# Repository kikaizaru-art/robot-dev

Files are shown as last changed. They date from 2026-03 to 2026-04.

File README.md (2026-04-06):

# CoreS3 コンパニオンロボット

M5Stack CoreS3 を使った LOVOT 風コンパニオンロボットのプロトタイプ。
カメラで人を検知し、表情を変え、声で会話し、首や腕を動かす。

## ハードウェア構成

| パーツ | 用途 |
|---|---|
| M5Stack CoreS3 | メインコントローラ (ESP32-S3, LCD, カメラ, マイク, スピーカー) |
| PCA9685 | I2C サーボドライバ |
| MG90S × 4 | 首ヨー/チルト + 左右腕 |
| FS90R × 2 | 走行用連続回転サーボ (予定) |
| ボールキャスター × 1 | 後輪 |

## 機能

- **表情アニメーション** — 6種類 (NORMAL / HAPPY / SAD / SURPRISED / SLEEPY / LOVE)、プロシージャル生成
- **顔検知 & 追従** — ML顔検知 + 肌色/動体検出、5段階の存在レベル判定
- **サーボ連動** — 検知した顔を首で追従、表情に連動した腕アニメーション
- **音声会話** — Gemini API (TTS) による日本語音声対話
- **タッチ & 音反応** — タッチで表情変化、大きな音で驚く
- **OTA更新** — WiFi経由でファームウェア書き込み

## ディレクトリ構成

```
src/             ファームウェア (PlatformIO, Arduino framework)
  main.cpp       メインループ: 検知→表情→サーボ制御
  face.h         LCD表情アニメーションエンジン
  camera_detect.h  顔検知・存在判定
  servo_ctrl.h   サーボ制御・アニメーション
  voice_chat.h   Gemini API 音声会話
chassis/         筐体 CAD (CadQuery → STEP → Fusion 360)
  assembly_v2.py メインアセンブリ
  parts/         個別パーツモデル (MG90S, FS90R, CoreS3 等)
assets/          表情画像 (PNG + RGB565)
data/            SPIFFS用表情データ
```

## ビルド

```bash
# ファームウェア書き込み (WiFi OTA)
pio run --target upload

# サーボテスト
pio run -e servo-test --target upload

# PCA9685テスト
pio run -e pca9685-test --target upload

# シリアルモニタ
pio device monitor -b 115200
```

## 開発状況

プロトタイプ開発中。ファームウェアは動作確認済み、筐体は CAD 設計完了・組み立て検証中。

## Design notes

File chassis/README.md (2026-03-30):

# CoreS3 コンパニオンロボット 筐体設計

## 構成

3分割構造:
1. **ベースプレート** — FS90R駆動輪×2 + ボールキャスター
2. **ボディシェル** — 腕サーボ×2 + PCA9685 + 配線
3. **ヘッドマウント** — CoreS3をスライドイン固定、パンチルト接続

## ファイル

- `robot_chassis.scad` — OpenSCAD設計ファイル（全パーツ統合）

## OpenSCADで開く

```bash
openscad chassis/robot_chassis.scad
```

## STLエクスポート（印刷用）

```bash
cd chassis
openscad -D "show_base=true;show_body=false;show_head=false;show_components=false" -o base.stl robot_chassis.scad
openscad -D "show_body=true;show_base=false;show_head=false;show_components=false" -o body.stl robot_chassis.scad
openscad -D "show_head=true;show_base=false;show_body=false;show_components=false" -o head.stl robot_chassis.scad
```

## サイズ

| パーツ | サイズ(mm) |
|---|---|
| ベース | 105 x 90 x 25 |
| ボディ | 90 x 75 x 55 |
| ヘッド | ~63 x ~47 x 50 |
| 全高 | ~160mm |

## 買い足しパーツ

| パーツ | 数量 | 価格目安 |
|---|---|---|
| PCA9685互換品 | 1 | 500-1,000 |
| MG90Sサーボ | 3 | 1,500 |
| FS90R連続回転サーボ | 2 | 800-1,200 |
| FS90R用タイヤ | 2 | 300-500 |
| ボールキャスター(小) | 1 | 100-300 |
| パンチルトブラケット | 1 | 300-600 |
| 5V 3A電源 | 1 | 500-1,000 |
| **合計** | | **4,000-6,100** |

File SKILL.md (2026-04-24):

---
name: robot-dev
description: M5Stack CoreS3 をベースにした LOVOT 風コンパニオンロボットのプロトタイプ開発プロジェクト。子供たち向けのデスクサイズロボットで、感情表現・顔検知追従・サーボ駆動・音声対話を実装している。次のキーワードや話題が出たときに発動すること： 「ロボット」「コンパニオンロボット」「LOVOT」「CoreS3」「M5Stack」「ESP32-S3」「PCA9685」「MG90S」「FS90R」「サーボ」「パンチルト」「ヨー軸」「筐体」「シャーシ」「CadQuery」「3Dプリント」「Bambu」「ユニバーサルプレート」「表情アニメーション」「顔検知」「Gemini 音声対話」「PlatformIO」「OTA」「ArduinoOTA」。ハード設計・ファームウェア・筐体CAD・機構・購入リスト・商品化方針など、このロボット製作に関する全般の相談相手となる。
---

# CoreS3 コンパニオンロボット (robot-dev)

## プロジェクトの目的
M5Stack CoreS3 をメインコントローラとし、LOVOT のような「そこにいるだけで可愛い」コンパニオンロボットを自作するプロトタイプ。子供たち向けのデスクサイズ玩具として、カメラで人を検知して顔を追い、表情を変え、音で反応し、腕や首を動かし、Gemini API で日本語の音声対話ができる。

最終的には商品化も視野に入れており、USB-C PD 充電、バッテリー駆動、足回り（FS90R 連続回転サーボ + ボールキャスター）への拡張を計画している。まずは動かしてみて手応えを確かめる「過剰設計を避ける」方針で進めている。

## 現在のフェーズ
- **ファームウェア**: 動作確認済み。表情6種（NORMAL / HAPPY / SAD / SURPRISED / SLEEPY / LOVE）、顔検知+肌色+動体による5段階の存在レベル判定、IMU傾き検知、タッチ反応、マイクのスパイク検知、Gemini 音声対話、WiFi OTA まで実装済み。
- **筐体 CAD**: 設計完了・組み立て検証中。`chassis/assembly_v2.py` が軸位置基準（shaft-first）で設計されたメインアセンブリ。
- **機構方針（2026-04-06 決定）**: MG90S ストールトルク 1.8kg·cm に対し負荷 ~150g のため、ヨー軸は**直付けで十分**と判断。ターンテーブル/BBベアリング/リンク機構は検討済みだが現状は不要。実機で動かしてガタつきがあれば補強する。
- **次にやること候補**: 実機組み立て・動作検証、足回り（FS90R 走行）実装、USB-C PD 充電対応、バッテリー搭載検討。

## 技術スタック・使用ツール
- **メインボード**: M5Stack CoreS3 (ESP32-S3, LCD, カメラ, マイク, スピーカー, IMU, タッチ)
- **サーボドライバ**: PCA9685 (I2C, Port A: G2=SDA, G1=SCL, 400kHz)
- **サーボ**: MG90S × 4（首 yaw/tilt + 腕 左右）、FS90R × 2（走行、予定）、ボールキャスター × 1（後輪）
- **電源（プロトタイプ）**: 9V ACアダプタ → DIN BASE (9-24V入力, SY8303AIC, 5V/3A出力)
- **ファームウェア**: PlatformIO CLI, Arduino framework, C++
  - lib: M5CoreS3, M5Unified, ESPAsyncWebServer, AsyncTCP, ESP32Servo, Adafruit PWM Servo Driver, ArduinoJson
- **書き込み**: WiFi OTA（`cores3-robot.local` / espota）。サーボ/PCA9685テストは USB(COM4)
- **シリアルモニタ**: `pio device monitor -b 115200`
- **筐体 CAD**: CadQuery 2.7.0 (Python) → STEP → Fusion 360 で確認
- **3Dプリンタ**: Bambu Lab A1 (FDM)
- **フレーム素材**: タミヤ ユニバーサルプレート 70157（160×60mm, 厚3mm, 5mmピッチ, 3mm穴）
- **音声対話**: Google Gemini API (TTS + 対話)

## リポジトリ構成
- `/README.md` — プロジェクト概要、機能一覧、ビルドコマンド
- `/platformio.ini` — PlatformIO 設定。`m5stack-cores3`（本番、OTA）、`servo-test`（USB）、`pca9685-test`（USB）の 3 環境
- `/.claude/commands/robot.md` — Claude Code 用スラッシュコマンド定義（本プロジェクトの作業手順・判断軸の一次情報源）
- `/src/` — ファームウェア
  - `main.cpp` — メインループ: 検知→存在判定→表情遷移→サーボ制御。WiFi+OTA+WebSocket ログも内包
  - `face.h` — LCD 表情アニメーションエンジン（プロシージャル生成）
  - `camera_detect.h` — ML 顔検知 + 肌色/動体検出 + 存在レベル判定
  - `servo_ctrl.h` — PCA9685 経由のサーボ制御、表情連動アニメ、idle motion
  - `voice_chat.h` — Gemini API による音声対話（IDLE / LISTENING / PROCESSING / SPEAKING の状態機械）
  - `expressions.h` — 表情 enum 共通定義
  - `servo_test.cpp`, `pca9685_test.cpp` — 個別テストファーム
  - （gitignore 済み・secrets）`wifi_config.h`, `gemini_config.h`
- `/chassis/` — 筐体設計
  - `assembly_v2.py` — **メインアセンブリ**。軸位置基準（shaft-first）設計
  - `assembly.py` — 旧版（参考）
  - `parts/` — 個別パーツ CadQuery モデル（`mg90s.py` / `fs90r.py` / `cores3.py` / `pan_tilt_bracket.py`）と STEP/STL、PCA9685 の STEP
  - `yaw_link_mechanism.py` — ヨー軸リンク機構の検討モデル（**現状は採用せず、参考用**）
  - `yaw_link_parts/` — リンク機構用のパーツ STEP
  - `robot_chassis.scad` — 初期の OpenSCAD 設計（旧版）
  - `*.step`, `*.stl` — エクスポート済み 3Dデータ（head / body / base / neck / pan_base / tilt_bracket / roll_bracket など）
- `/data/` — SPIFFS(LittleFS) 用の表情 RGB565 バイナリ（each 153600B）
- `/assets/expressions/`, `/assets/rgb565/` — 表情画像ソース
- `/include/`, `/lib/`, `/test/` — PlatformIO 標準（現状ほぼ空）

## Claudeに期待する役割
このプロジェクトの **技術的な議論の相棒**。以下のような相談に付き合ってほしい：

- ファームウェア改修の相談（表情ロジック、センサー融合、サーボモーション、Gemini 連携、OTA、メモリ/タイミング問題）
- 筐体 CAD の設計レビュー・モデル修正（CadQuery スクリプト、軸配置、クリアランス、ブラケット形状）
- 機構設計の判断（直付け vs リンク機構、ベアリング要否、負荷見積もり、3D プリント向け肉厚）
- 実装の優先順位・次のマイルストーンの相談
- 買い足しパーツの選定（型番・価格・入手性）、BOM 更新
- 子供向け玩具としての UX 議論（怖くない・飽きない・壊れない）
- 商品化に向けた電源・充電・バッテリー方式の検討

提案は断定せず選択肢とトレードオフを示し、**過剰設計を避ける**原則に従うこと。既存の設計判断（特にヨー軸直付け方針）を覆す場合は根拠を明示する。

## 注意事項・前提

### ハマりポイント（ファームウェア）
- **WiFi 初期化は setup() でノンブロッキング**。ブロッキングで待つと WDT クラッシュ。
- **マイク初期化は `cfg.internal_mic = true` で `CoreS3.begin(cfg)` に渡す**。カメラ初期化後に別途 `Mic.begin()` を呼ぶとクラッシュする。
- **サーボ用タイマーは 2, 3 を使う**。0, 1 はディスプレイ/オーディオと競合する。
- **PCA9685 クローン品は V+ がサーボ端子に繋がっていないことがある** → CH0 の V+ ピンにジャンパーで 5V 直接給電するワークアラウンドを採用中。
- LCD 表情はプロシージャル生成（PNG ではなく描画）。`data/*.bin` は別系統の RGB565 リソース。
- 表情遷移は `EXPR_SETTLE_MS = 600ms` の安定化時間を設けている。SURPRISED / SAD は即時遷移。

### CadQuery 設計の方針
- **shaft-first**: サーボの出力軸位置を先にワールド座標で決め、`place_servo_by_shaft()` でサーボ本体を逆算配置する。
- サーボ寸法（MG90S / FS90R）はデータシート値をコード先頭にまとめてある。
- 実行は `cd chassis && python <file>.py` → STEP 出力 → Fusion 360 で目視確認。
- タミヤ ユニバーサルプレート（5mm ピッチ 3mm 穴）を前提にした穴配置。

### 過去に検討済み・結論が出ていること
- **ヨー軸の荷重対策**: 直付けで OK（MG90S トルク余裕、負荷 ~150g）。ターンテーブル+中心軸方式は `yaw_link_mechanism.py` にモデル化済みだが採用していない。
- **CAD ツール**: OpenSCAD から CadQuery に移行済み（`robot_chassis.scad` は旧版、参照のみ）。
- **筐体構成**: ベース / ボディ / ヘッド の 3 分割。

### 機能を勝手に削除・簡略化しない
ユーザーの明示指示がない限り、既存機能（表情、顔検知、音声対話、OTA、Web ログ等）を「不要」と判断して削除しない。リファクタ時も挙動は保つ。

### Secrets
`src/wifi_config.h` と `src/gemini_config.h` は gitignore 済み。これらに関する内容を生成するときは、値は伏せてテンプレートのみ示す。

### 未定・未確定事項（2026-04-24 時点）
- 足回り（FS90R 走行）の実装タイミングは**現時点では未定**。
- バッテリー搭載の有無・型番は**現時点では未定**（足回り実装後に検討予定）。
- 商品化のタイムラインや販売形態は**現時点では未定**。

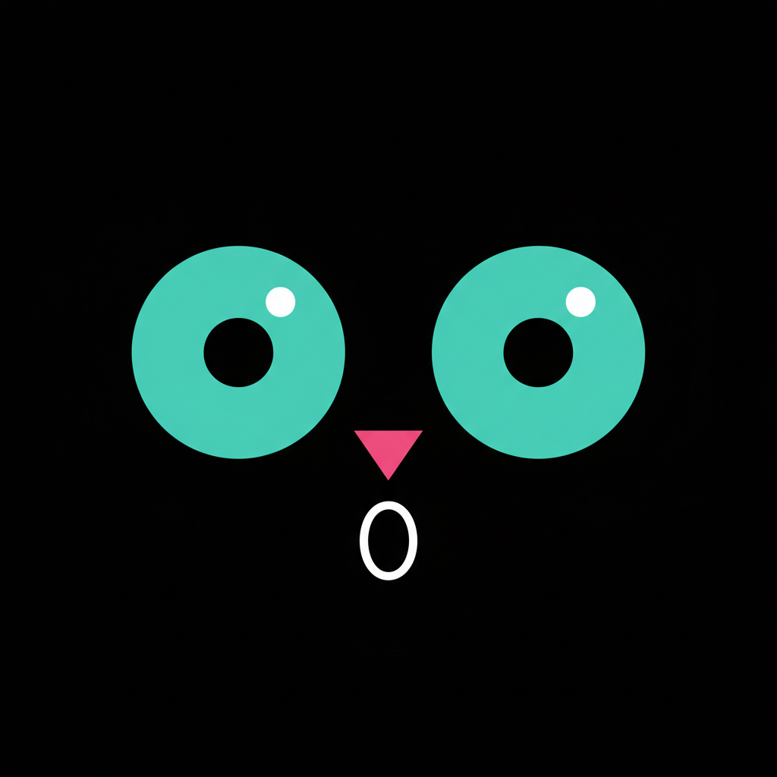
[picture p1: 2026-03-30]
assets/expressions/surprised.png

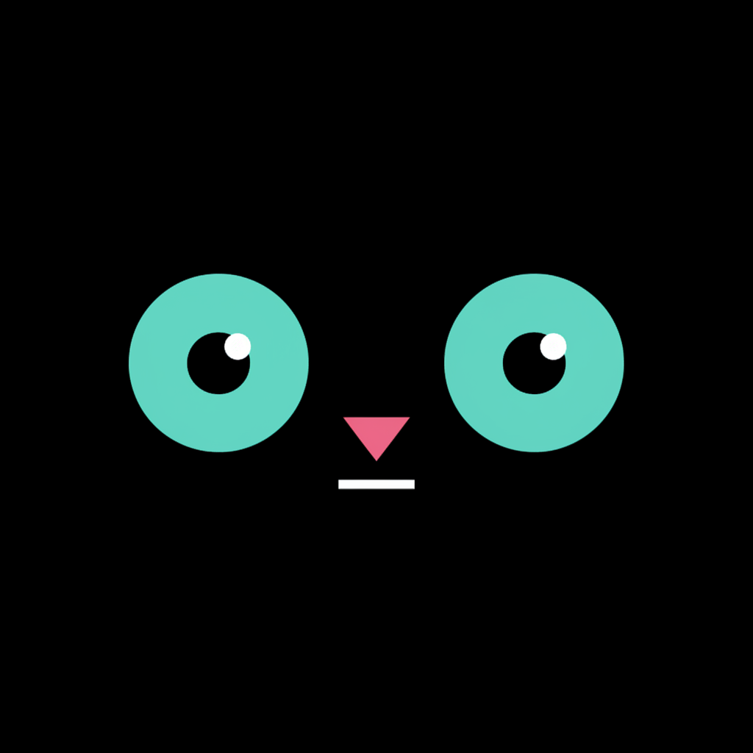
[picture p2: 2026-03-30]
assets/expressions/normal.png

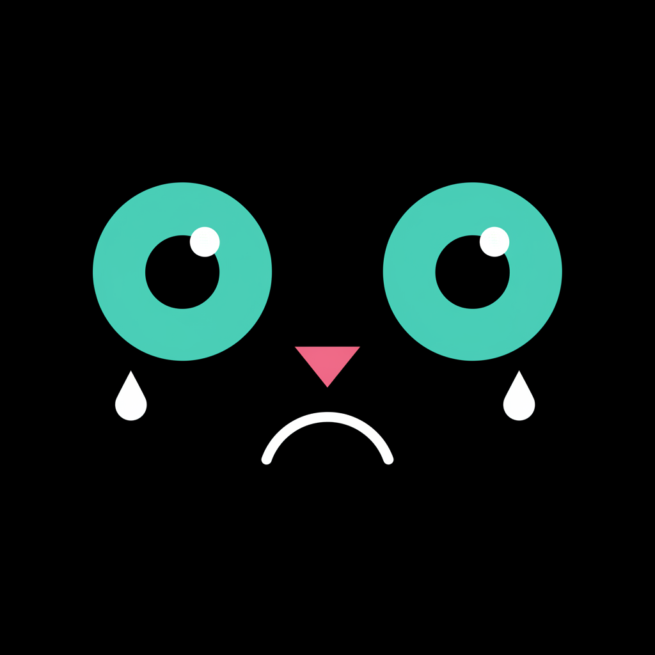
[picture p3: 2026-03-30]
assets/expressions/sad.png

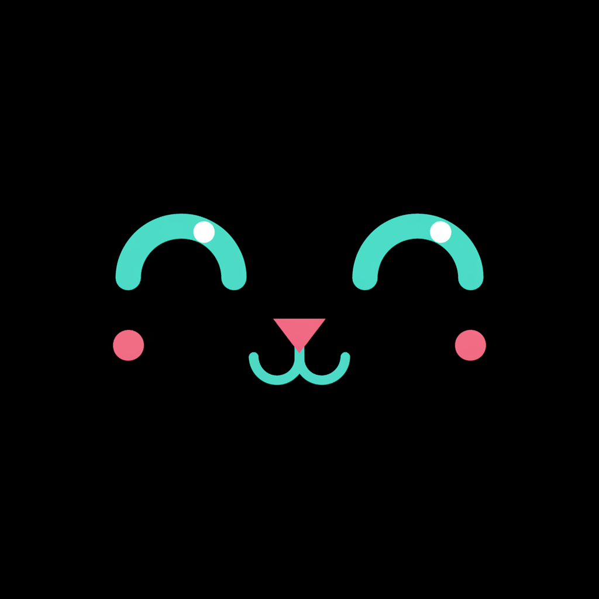
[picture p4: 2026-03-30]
assets/expressions/happy.png

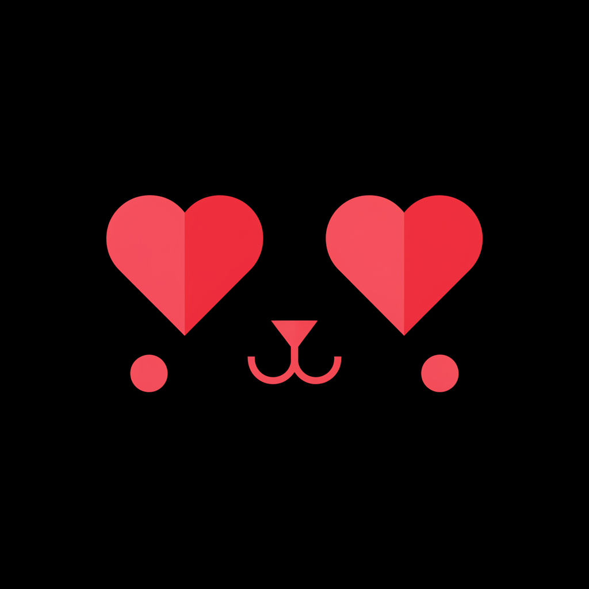
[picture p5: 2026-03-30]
assets/expressions/love.png

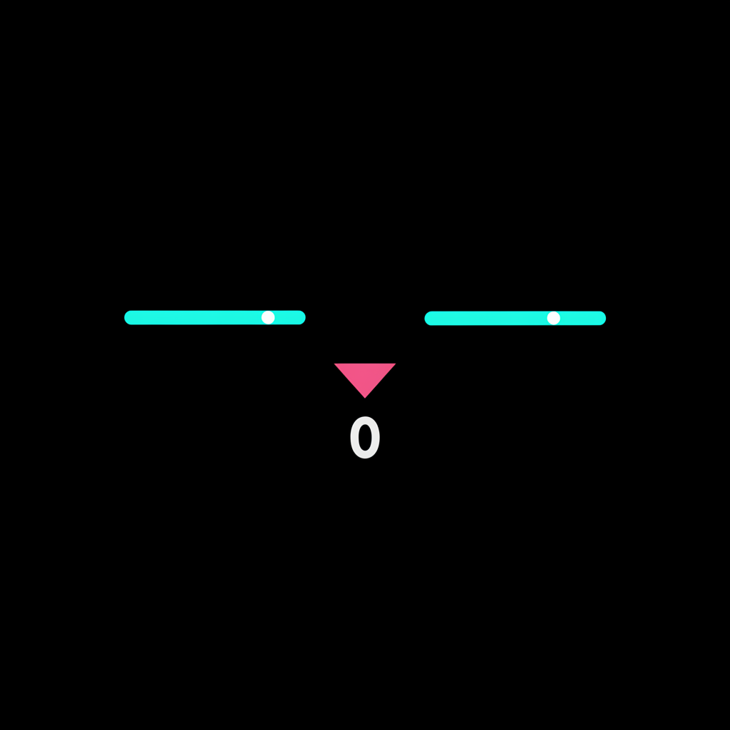
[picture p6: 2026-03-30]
assets/expressions/sleepy.png

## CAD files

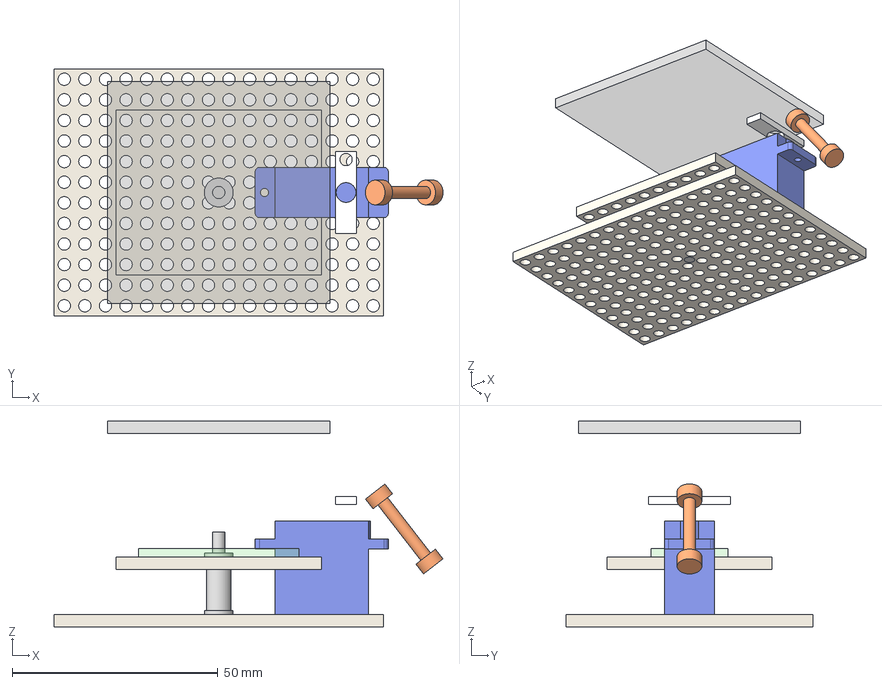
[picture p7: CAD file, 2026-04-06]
chassis/yaw_link_assembly.step
94.4 x 60.0 x 50.0 mm
base_plate
center_shaft
turntable
yaw_servo
link_arm
servo_horn
pantilt_footprint
cores3_footprint

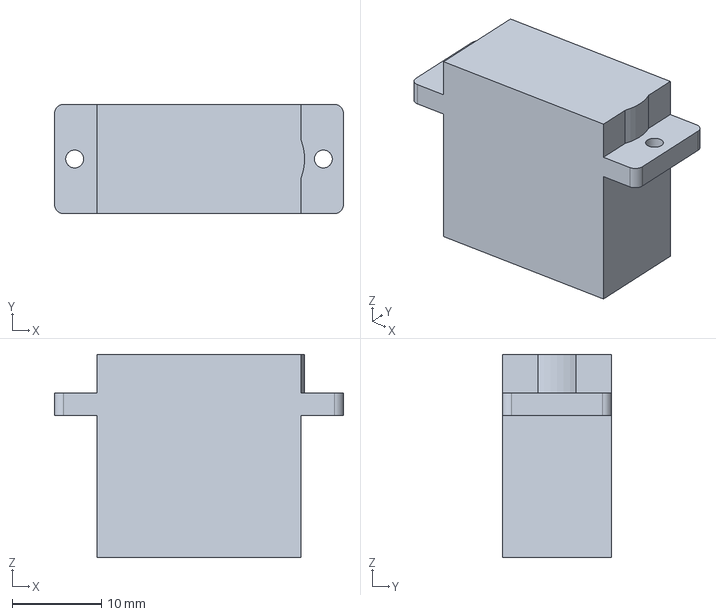
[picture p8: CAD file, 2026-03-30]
chassis/parts/mg90s.step
32.3 x 12.2 x 22.7 mm

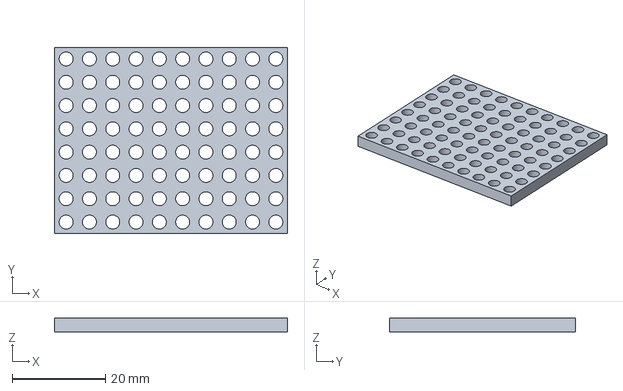
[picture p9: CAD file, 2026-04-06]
chassis/yaw_link_parts/turntable.step
50.0 x 40.0 x 3.00 mm

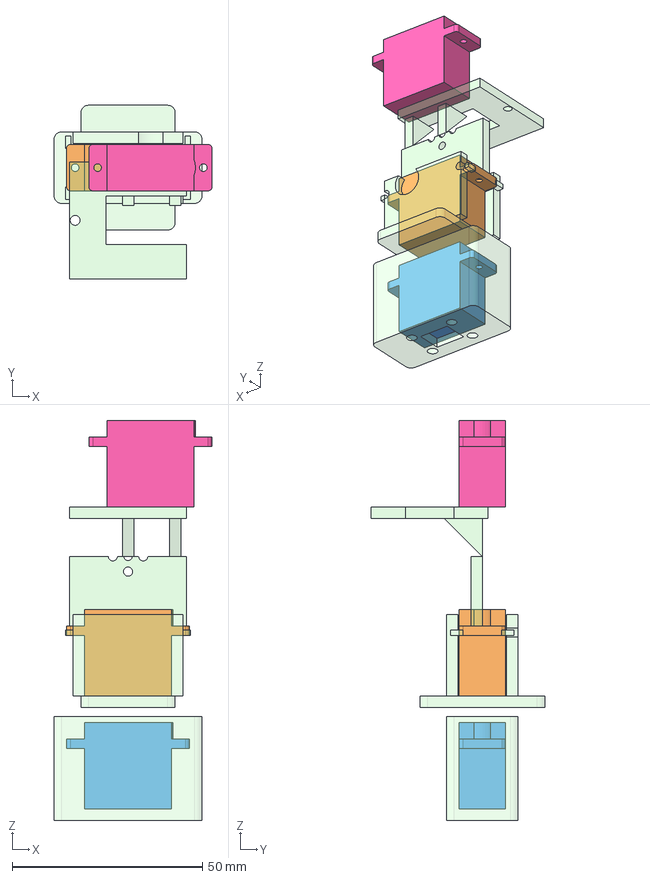
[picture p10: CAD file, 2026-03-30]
chassis/bracket_check_all.step
41.5 x 45.6 x 105.1 mm
pan_base
yaw_servo
tilt_bracket
pitch_servo
roll_bracket
roll_servo

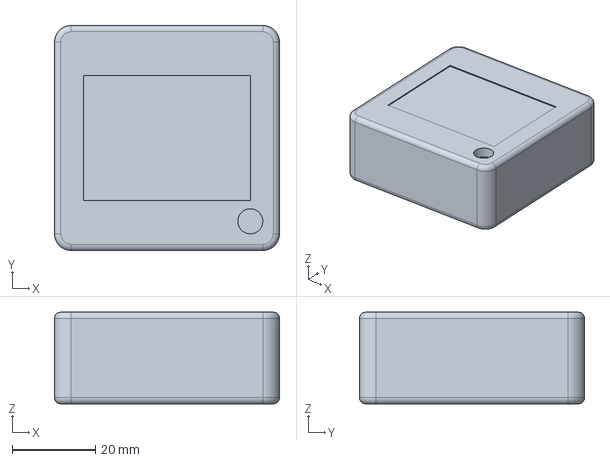
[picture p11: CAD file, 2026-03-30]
chassis/parts/cores3.step
54.0 x 54.0 x 22.0 mm

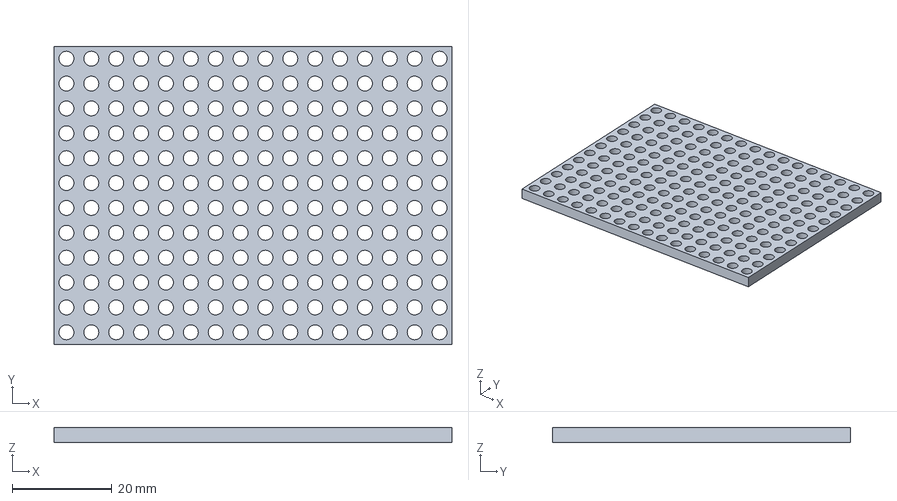
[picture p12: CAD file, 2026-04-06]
chassis/yaw_link_parts/base_plate.step
80.0 x 60.0 x 3.00 mm

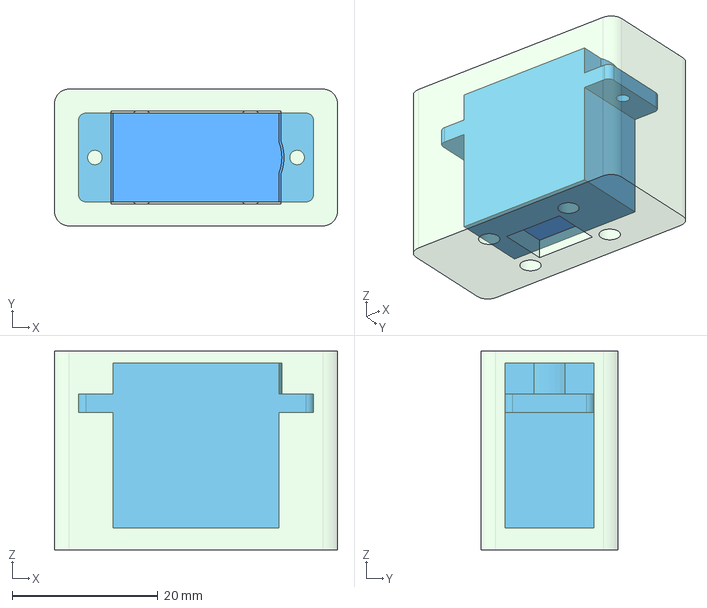
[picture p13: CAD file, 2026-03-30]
chassis/bracket_check_pan.step
38.9 x 18.8 x 27.3 mm
pan_base
yaw_servo

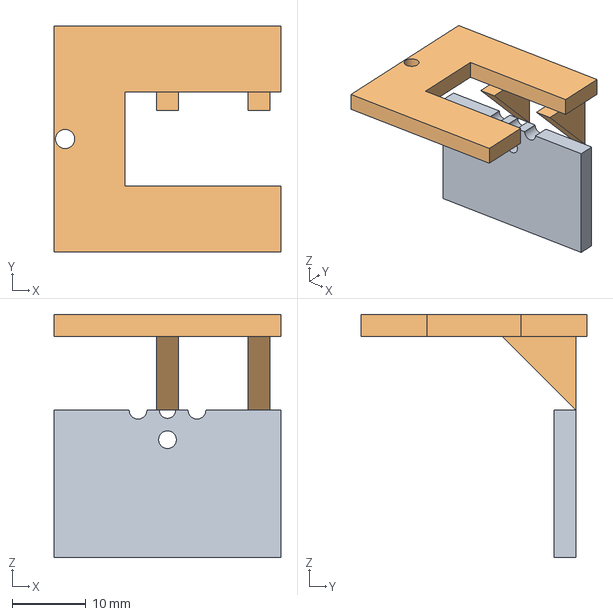
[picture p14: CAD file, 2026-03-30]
chassis/parts/roll_bracket.step
30.8 x 30.7 x 33.0 mm

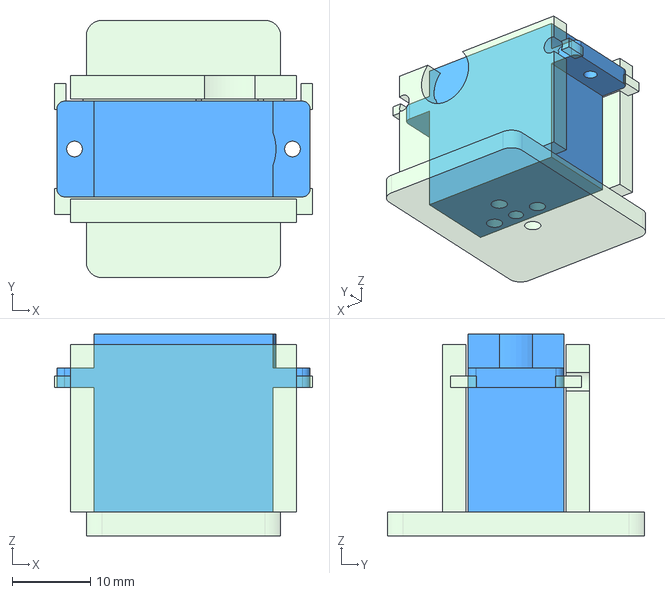
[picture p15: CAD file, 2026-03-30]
chassis/bracket_check_tilt.step
32.9 x 32.8 x 25.7 mm
tilt_bracket
pitch_servo

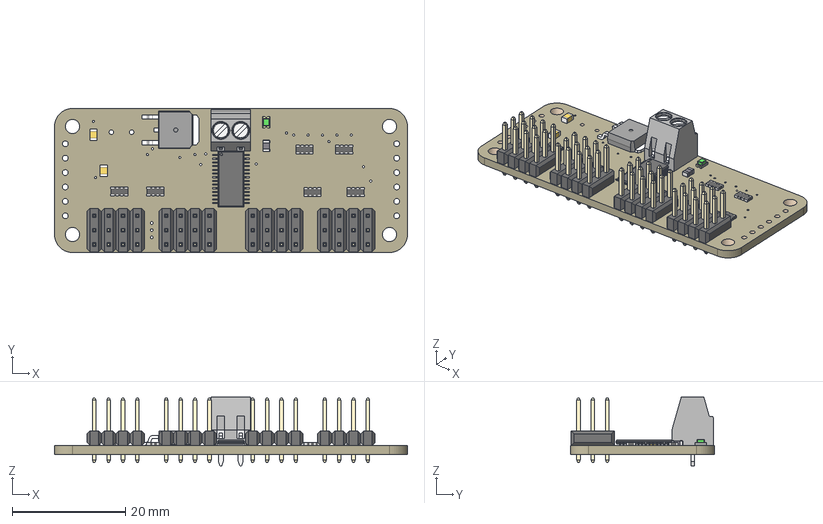
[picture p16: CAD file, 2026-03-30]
chassis/parts/pca9685.step
62.2 x 25.4 x 12.1 mm
Board
PCA9685
10K x 2
TERMBLOCK_1X2-3.5MM
AOD417
GREEN
3X04 x 4
10K_1 x 6

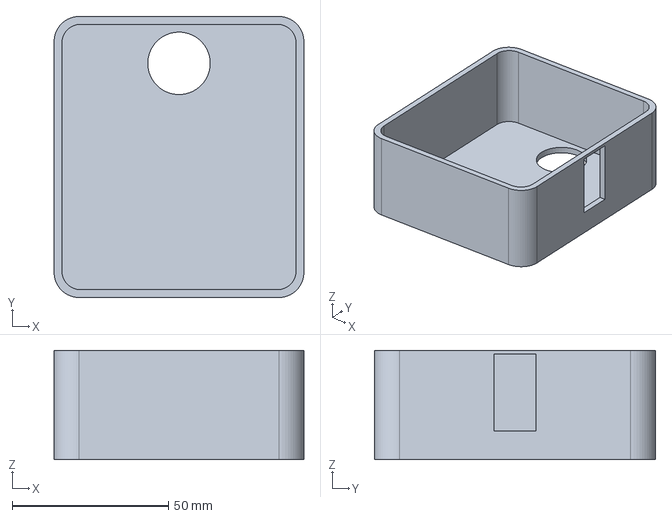
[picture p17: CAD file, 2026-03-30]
chassis/base.step
80.0 x 90.0 x 35.0 mm

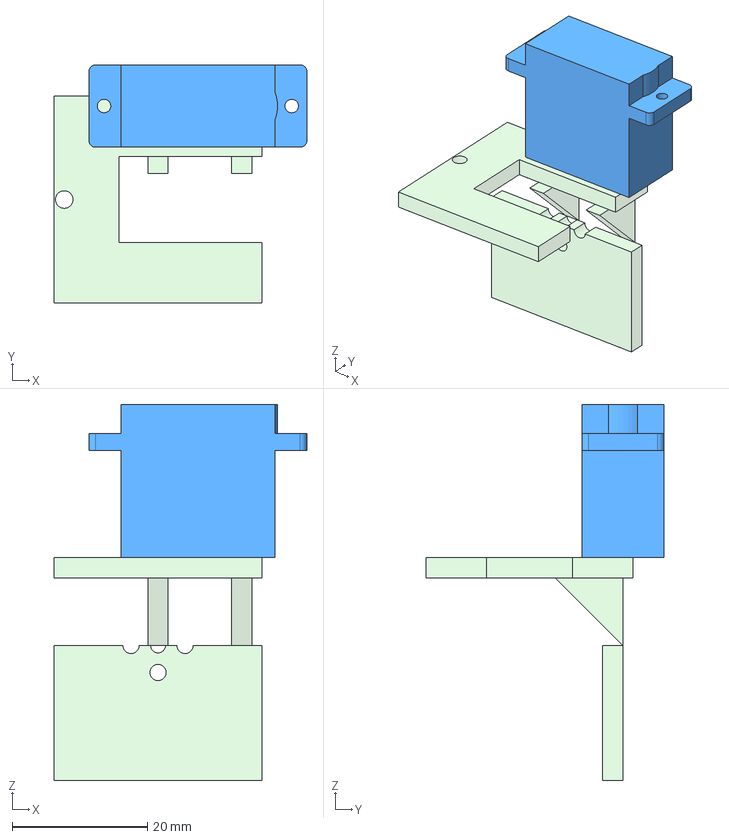
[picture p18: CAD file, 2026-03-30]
chassis/bracket_check_roll.step
37.5 x 35.3 x 55.7 mm
roll_bracket
roll_servo

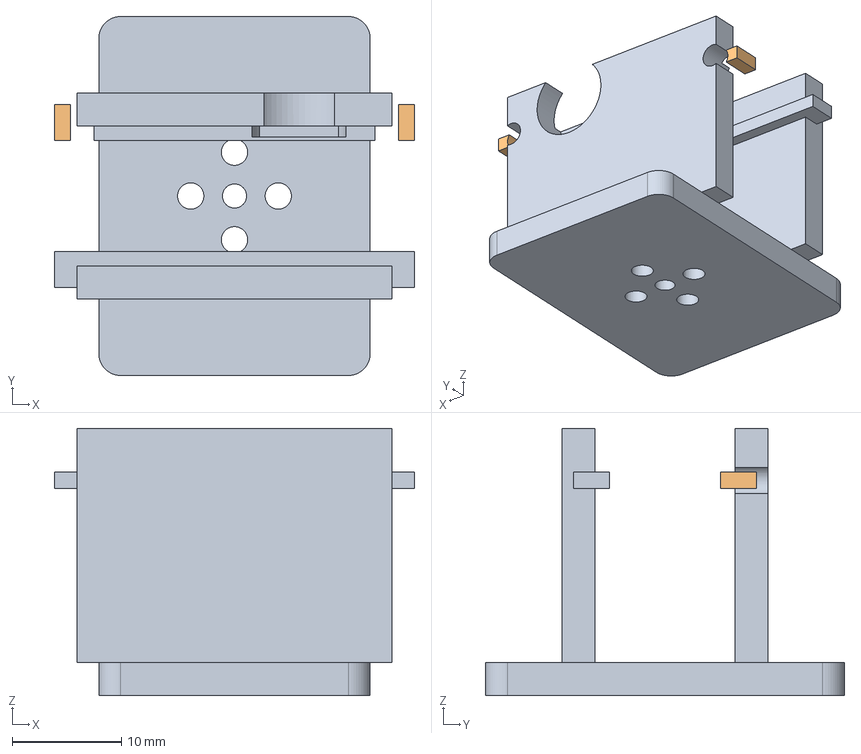
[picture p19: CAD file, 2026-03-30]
chassis/parts/tilt_bracket.step
32.9 x 32.8 x 24.4 mm

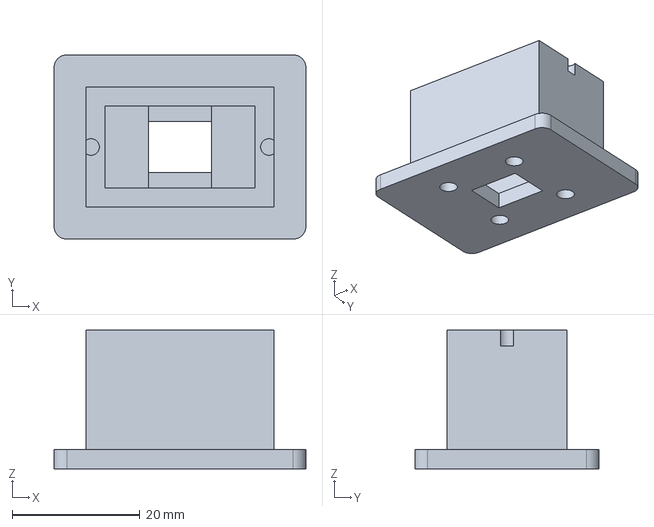
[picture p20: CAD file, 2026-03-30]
chassis/pan_base.step
39.4 x 28.8 x 21.7 mm

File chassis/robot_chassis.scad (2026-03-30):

// ============================================
// CoreS3 コンパニオンロボット 筐体設計
// Compact Robot Chassis - Cozmo/Vector Style
// ============================================
// 3分割構成: ベース / 胴体 / ヘッド
// プリンタ: Bambu Lab A1 (FDM)
// 単位: mm

// ---- パーツ実寸 ----
// CoreS3: 58 x 65 x 18mm (画面: ~54 x 40mm)
// MG90S: 23 x 12.2 x 29mm (軸含む32mm)
// FS90R: 23 x 12.2 x 22mm (MG90Sより短い)
// PCA9685: 62 x 25 x 10mm
// ボールキャスター: ~16mm高 (小型)

// ---- 設計パラメータ ----
wall = 2.5;          // 壁厚
tol = 0.3;           // はめあい公差
screw_d = 2.5;       // M2.5ネジ穴径
screw_head_d = 5;    // M2.5ネジ頭径

// CoreS3寸法
cs3_w = 58;          // 幅
cs3_d = 65;          // 奥行
cs3_h = 18;          // 厚み
cs3_screen_w = 54;   // 画面幅
cs3_screen_h = 40;   // 画面高

// サーボ寸法
mg90s_w = 23;
mg90s_d = 12.2;
mg90s_h = 29;
mg90s_flange_w = 32.5;  // フランジ幅
mg90s_flange_h = 2.5;   // フランジ厚
mg90s_flange_pos = 17;  // 底からフランジまで

fs90r_w = 23;
fs90r_d = 12.2;
fs90r_h = 22;
fs90r_flange_w = 32.5;
fs90r_flange_h = 2.5;
fs90r_flange_pos = 15.5;

// タイヤ
wheel_d = 60;        // FS90R用ホイール直径
wheel_w = 8;         // ホイール幅

// ボールキャスター
caster_h = 16;       // 小型ボールキャスター高さ
caster_d = 12;       // 取付穴間

// PCA9685
pca_w = 62;
pca_d = 25;
pca_h = 10;

// ============================================
//  表示制御
// ============================================
// コメントアウトで個別パーツ表示切替
show_base = true;
show_body = true;
show_neck = true;
show_head = true;
show_components = true;  // パーツのゴースト表示

// ============================================
//  全体レイアウト
// ============================================
// ベース高さ = キャスター高 + 少しの余裕
base_h = 25;
base_w = 130;        // タイヤと腕の干渉回避のため広め
base_d = 90;

// 胴体
body_h = 55;
body_w = 90;
body_d = 75;
body_z = base_h;  // ベースの上

// 首（3自由度: ヨー(ギア駆動) → ピッチ(直結) → ロール(直結)）
// ヨーサーボは胴体内に水平配置、リングギアで回転台を駆動
// ピッチ・ロールサーボは回転台上にマウント
ring_gear_d = 60;      // リングギア外径
pinion_d = 15;         // ピニオンギア直径
turntable_d = 55;      // 回転台（ターンテーブル）直径
turntable_h = 3;       // 回転台の厚み
bracket_h = mg90s_h + 5;  // ピッチブラケット高さ ~34mm
neck_h = turntable_h + bracket_h + mg90s_d + 5;  // ~55mm
neck_z = body_z + body_h;

// ヘッド（CoreS3マウント）— CoreS3は立てて収納（画面が前）
// CoreS3 standing: X=幅58, Y=厚み18, Z=高さ65
head_w = cs3_w + wall * 2 + tol * 2;       // ~64mm（幅）
head_d = cs3_h + wall * 2 + tol * 2 + 10;  // ~34mm（奥行き=厚み18+余裕）
head_h = cs3_d + wall * 2 + tol * 2;       // ~71mm（高さ=CoreS3の65mm）
head_z = neck_z + neck_h;                   // 首の上

module rounded_box(w, d, h, r=5) {
    // 角丸の箱
    hull() {
        for (x = [r, w-r])
            for (y = [r, d-r])
                translate([x, y, 0])
                    cylinder(r=r, h=h, $fn=32);
    }
}

module screw_hole(h=10) {
    cylinder(d=screw_d, h=h, $fn=20);
}

module screw_standoff(h=6, od=6) {
    difference() {
        cylinder(d=od, h=h, $fn=24);
        translate([0, 0, -0.1])
            cylinder(d=screw_d, h=h+0.2, $fn=20);
    }
}

// ============================================
//  1. ベースプレート
// ============================================
module base_plate() {
    color("DimGray", 0.8)
    difference() {
        union() {
            // メインプレート（角丸）
            rounded_box(base_w, base_d, base_h, r=8);

            // 胴体取付用ボス（4箇所）
            body_mount_points = [
                [15, 15], [base_w-15, 15],
                [15, base_d-15], [base_w-15, base_d-15]
            ];
            for (p = body_mount_points) {
                translate([p[0], p[1], base_h])
                    screw_standoff(h=5, od=7);
            }
        }

        // 内部空洞（軽量化 + 配線スペース）
        translate([wall, wall, wall])
            rounded_box(base_w - wall*2, base_d - wall*2, base_h, r=6);

        // ---- FS90R サーボマウント（左右）----
        // 左サーボ
        translate([-1, base_d/2 - fs90r_w/2, base_h/2 - fs90r_d/2])
            cube([wall+2, fs90r_w + tol*2, fs90r_d + tol*2]);
        // 左サーボ フランジスロット
        translate([-1, base_d/2 - fs90r_flange_w/2, base_h/2 - fs90r_d/2 + fs90r_flange_pos])
            cube([wall*2+2, fs90r_flange_w + tol, fs90r_flange_h + tol]);

        // 右サーボ
        translate([base_w - wall - 1, base_d/2 - fs90r_w/2, base_h/2 - fs90r_d/2])
            cube([wall+2, fs90r_w + tol*2, fs90r_d + tol*2]);
        // 右サーボ フランジスロット
        translate([base_w - wall*2 - 1, base_d/2 - fs90r_flange_w/2, base_h/2 - fs90r_d/2 + fs90r_flange_pos])
            cube([wall*2+2, fs90r_flange_w + tol, fs90r_flange_h + tol]);

        // ---- ボールキャスター取付穴（前方中央）----
        translate([base_w/2, 15, -1])
            cylinder(d=12, h=wall+2, $fn=24);
        // キャスター固定ネジ穴
        for (dx = [-8, 8]) {
            translate([base_w/2 + dx, 15, -1])
                cylinder(d=screw_d, h=wall+2, $fn=16);
        }

        // ---- 配線通し穴（上面）----
        translate([base_w/2 - 10, base_d/2 - 5, base_h - wall - 1])
            cube([20, 10, wall + 2]);

        // ---- 底面通気穴 ----
        for (x = [25, 50, 75]) {
            translate([x, base_d/2, -1])
                cylinder(d=5, h=wall+2, $fn=16);
        }
    }
}

// ============================================
//  2. 胴体（ボディ）
// ============================================
module body_shell() {
    color("SlateGray", 0.8)
    translate([base_w/2 - body_w/2, base_d/2 - body_d/2, body_z])
    difference() {
        union() {
            // 外殻（台形っぽい角丸ボックス）
            rounded_box(body_w, body_d, body_h, r=10);
        }

        // 内部空洞
        translate([wall, wall, wall])
            rounded_box(body_w - wall*2, body_d - wall*2, body_h + 1, r=8);

        // ---- 腕サーボマウント（左）---- 上寄り配置（タイヤ干渉回避）
        arm_z = body_h * 0.65 - mg90s_d/2;  // 上2/3の位置
        translate([-1, body_d/2 - mg90s_w/2, arm_z])
            cube([wall+2, mg90s_w + tol*2, mg90s_d + tol*2]);
        // 左 フランジスロット
        translate([-1, body_d/2 - mg90s_flange_w/2, arm_z + mg90s_flange_pos])
            cube([wall*2, mg90s_flange_w + tol, mg90s_flange_h + tol]);
        // 左 軸穴
        translate([-1, body_d/2, arm_z + mg90s_h - 5])
            rotate([0, 90, 0])
                cylinder(d=8, h=wall+2, $fn=24);

        // ---- 腕サーボマウント（右）----
        translate([body_w - wall - 1, body_d/2 - mg90s_w/2, arm_z])
            cube([wall+2, mg90s_w + tol*2, mg90s_d + tol*2]);
        // 右 フランジスロット
        translate([body_w - wall*2, body_d/2 - mg90s_flange_w/2, arm_z + mg90s_flange_pos])
            cube([wall*2, mg90s_flange_w + tol, mg90s_flange_h + tol]);
        // 右 軸穴
        translate([body_w - wall - 1, body_d/2, arm_z + mg90s_h - 5])
            rotate([0, 90, 0])
                cylinder(d=8, h=wall+2, $fn=24);

        // ---- PCA9685マウントスロット（底面内側）----
        // ネジ穴で固定
        translate([body_w/2 - pca_w/2, body_d/2 - pca_d/2, 0])
        for (dx = [3, pca_w-3])
            for (dy = [3, pca_d-3])
                translate([dx, dy, -1])
                    cylinder(d=screw_d, h=wall+2, $fn=16);

        // ---- 背面メンテナンスハッチ ----
        translate([body_w/2 - 25, body_d - wall - 1, 10])
            cube([50, wall + 2, body_h - 20]);

        // ---- 配線穴（底面）----
        translate([body_w/2 - 10, body_d/2 - 5, -1])
            cube([20, 10, wall + 2]);

        // ---- リングギア+回転台 貫通穴（上面中央）----
        translate([body_w/2, body_d/2, body_h - wall - 1])
            cylinder(d=ring_gear_d + 5, h=wall + 2, $fn=32);

        // ---- ベース取付ネジ穴（4箇所）----
        body_offset_x = base_w/2 - body_w/2;
        body_offset_y = base_d/2 - body_d/2;
        mount_pts = [
            [15 - body_offset_x, 15 - body_offset_y],
            [base_w - 15 - body_offset_x, 15 - body_offset_y],
            [15 - body_offset_x, base_d - 15 - body_offset_y],
            [base_w - 15 - body_offset_x, base_d - 15 - body_offset_y]
        ];
        for (p = mount_pts) {
            translate([p[0], p[1], -1])
                cylinder(d=screw_d, h=wall + 2, $fn=16);
        }
    }
}

// ============================================
//  3. 首（ネック）— 可動スペース確保用
// ============================================
// 内部構造（ギア+サーボ+ブラケット）は実物合わせで設計
// ここでは必要な空間とマウントポイントだけ定義
module neck() {
    cx = base_w/2;
    cy = base_d/2;

    // ---- 首の可動空間を示す半透明シリンダ ----
    color("SteelBlue", 0.2)
    translate([cx, cy, neck_z])
        cylinder(d=ring_gear_d, h=neck_h, $fn=36);

    // ---- 回転台ベース（胴体上面に固定）----
    color("Gold", 0.6)
    translate([cx, cy, neck_z])
    difference() {
        cylinder(d=ring_gear_d, h=4, $fn=36);
        translate([0, 0, -1])
            cylinder(d=ring_gear_d - 10, h=6, $fn=36);
    }

    // ---- ヘッド取付台（首の上端）----
    color("Silver", 0.7)
    translate([cx, cy, neck_z + neck_h - 4])
    difference() {
        cylinder(d=40, h=4, $fn=36);
        // ネジ穴
        for (a = [0:90:270])
            rotate([0, 0, a])
                translate([14, 0, -1])
                    cylinder(d=screw_d, h=6, $fn=12);
        // 配線穴
        translate([0, 0, -1])
            cylinder(d=12, h=6, $fn=20);
    }
}
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

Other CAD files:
chassis/parts/fs90r.step
chassis/neck.step
chassis/body.step
chassis/head.step
chassis/base.stl
chassis/body.stl
chassis/head.stl
chassis/pan_base.stl
chassis/parts/cores3.stl
chassis/parts/fs90r.stl
chassis/parts/mg90s.stl
chassis/parts/pan_base.step
chassis/parts/pan_base.stl
chassis/parts/roll_bracket.stl
chassis/parts/tilt_bracket.stl
chassis/roll_bracket.step
chassis/roll_bracket.stl
chassis/tilt_bracket.step
chassis/tilt_bracket.stl

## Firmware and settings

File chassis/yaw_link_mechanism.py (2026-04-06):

"""
ヨー軸リンク機構 — ユニバーサルプレート版
===========================================

問題:
  パンチルトブラケット + CoreS3 の全重量が yaw サーボ軸に直接かかっている。
  サーボ軸は回転力を伝えるもので、構造材として荷重を受けるべきではない。

解決:
  ベースプレート上に回転軸（M3ボルト + ナイロンスペーサー）を立て、
  ターンテーブル（上部プレート）をその軸で支持。
  yaw サーボはベースに固定し、リンクアームでターンテーブルを回す。
  → サーボ軸には回転トルクのみ、荷重は中心軸が受ける。

構成:
  1. base_plate    — ベースプレート（ユニバーサルプレート切り出し）
  2. turntable     — ターンテーブル（ユニバーサルプレート切り出し、上に載る）
  3. center_shaft  — 中心回転軸（M3ボルト + ナイロンスペーサー）
  4. yaw_servo     — MG90S、ベースに横付け固定
  5. link_arm      — サーボホーン → ターンテーブル端のプッシュロッド

ユニバーサルプレート仕様:
  - タミヤ 70157: 160 × 60 mm、厚さ 3mm
  - 5mm ピッチの穴（3mm径）、端から 2.5mm オフセット
  - 穴数: 32 × 12 = 384 穴/枚
"""
import cadquery as cq
import os
import sys
import math

# パーツのインポート
sys.path.insert(0, os.path.dirname(__file__))
from parts.mg90s import make_mg90s

# ============================================
#  ユニバーサルプレート仕様
# ============================================
PLATE_FULL_W = 160.0   # 元のプレート幅
PLATE_FULL_D = 60.0    # 元のプレート奥行き
PLATE_H = 3.0          # プレート厚み
HOLE_PITCH = 5.0       # 穴ピッチ
HOLE_D = 3.0           # 穴径
HOLE_OFFSET = 2.5      # 端から最初の穴中心までの距離

# ============================================
#  MG90S 寸法（再掲）
# ============================================
SERVO_BODY_W = 22.8
SERVO_BODY_D = 12.2
SERVO_BODY_H = 22.7
SERVO_FLANGE_W = 32.3
SERVO_FLANGE_Z = 15.9
SERVO_FLANGE_H = 2.5
SERVO_SHAFT_OFFSET_X = 5.9
SERVO_SHAFT_H = 4.0
SERVO_EAR_HOLE_DIST = 27.8

# ============================================
#  設計パラメータ
# ============================================
# ベースプレート切り出しサイズ（穴数ベース）
BASE_HOLES_X = 16       # 16穴 = 77.5mm (2.5 + 15*5 + 2.5)
BASE_HOLES_Y = 12       # 12穴 = 57.5mm (フル幅使用)
BASE_W = HOLE_OFFSET + (BASE_HOLES_X - 1) * HOLE_PITCH + HOLE_OFFSET  # 77.5mm
BASE_D = HOLE_OFFSET + (BASE_HOLES_Y - 1) * HOLE_PITCH + HOLE_OFFSET  # 57.5mm

# ターンテーブル切り出しサイズ
TT_HOLES_X = 10          # 10穴 = 47.5mm
TT_HOLES_Y = 8           # 8穴 = 37.5mm
TT_W = HOLE_OFFSET + (TT_HOLES_X - 1) * HOLE_PITCH + HOLE_OFFSET  # 47.5mm
TT_D = HOLE_OFFSET + (TT_HOLES_Y - 1) * HOLE_PITCH + HOLE_OFFSET  # 37.5mm

# 中心回転軸
CENTER_SHAFT_D = 3.0      # M3ボルト
SPACER_OD = 6.0           # ナイロンスペーサー外径
SPACER_H = 10.0           # スペーサー高さ（ベースとターンテーブル間のクリアランス）
WASHER_D = 7.0            # ナイロンワッシャー外径
WASHER_H = 1.0            # ワッシャー厚

# サーボ配置
SERVO_OFFSET_X = 25.0     # ベース中心からサーボ軸までのXオフセット
SERVO_MOUNT_Z = PLATE_H   # サーボはベースプレート上面に横付け

# リンクアーム
LINK_ARM_LEN = 20.0       # サーボホーンからターンテーブルまでの距離
LINK_ROD_D = 3.0          # M3ボルトをプッシュロッドに流用
LINK_ATTACH_OFFSET = 18.0 # ターンテーブル中心からリンク接続点までの距離


def make_universal_plate(holes_x, holes_y, label="plate"):
    """
    ユニバーサルプレートの切り出し片をモデル化
    holes_x, holes_y: 穴の数
    """
    w = HOLE_OFFSET + (holes_x - 1) * HOLE_PITCH + HOLE_OFFSET
    d = HOLE_OFFSET + (holes_y - 1) * HOLE_PITCH + HOLE_OFFSET

    plate = (
        cq.Workplane("XY")
        .box(w, d, PLATE_H, centered=(True, True, False))
    )

    # 穴を開ける
    hole_points = []
    for ix in range(holes_x):
        for iy in range(holes_y):
            x = -w / 2 + HOLE_OFFSET + ix * HOLE_PITCH
            y = -d / 2 + HOLE_OFFSET + iy * HOLE_PITCH
            hole_points.append((x, y))

    plate = (
        plate
        .faces(">Z")
        .workplane()
        .pushPoints(hole_points)
        .hole(HOLE_D)
    )

    return plate


def make_base_plate():
    """
    ベースプレート
    - ユニバーサルプレートから切り出し (16×12穴)
    - 中央に回転軸用の穴（既存の5mm穴をそのまま利用）
    - サーボ取付エリア
    """
    plate = make_universal_plate(BASE_HOLES_X, BASE_HOLES_Y, "base")
    return plate


def make_turntable():
    """
    ターンテーブル（回転テーブル）
    - ユニバーサルプレートから切り出し (10×8穴)
    - 中央穴＝回転軸（M3ボルト）
    - パンチルトブラケットはこの上に載せる
    - リンクアーム接続穴
    """
    plate = make_universal_plate(TT_HOLES_X, TT_HOLES_Y, "turntable")
    return plate


def make_center_shaft():
    """
    中心回転軸
    - M3ボルト + ナイロンスペーサー + ワッシャー
    - ベースプレート中央穴を貫通→スペーサー→ターンテーブルを支持
    """
    # M3ボルト（軸）
    bolt = (
        cq.Workplane("XY")
        .circle(CENTER_SHAFT_D / 2)
        .extrude(PLATE_H + SPACER_H + PLATE_H + WASHER_H * 2 + 5)
    )

    # ナイロンスペーサー（ベースプレート上面〜ターンテーブル下面）
    spacer = (
        cq.Workplane("XY")
        .workplane(offset=PLATE_H + WASHER_H)
        .circle(SPACER_OD / 2)
        .extrude(SPACER_H)
    )

    # 下ワッシャー（ベース上面）
    washer_bottom = (
        cq.Workplane("XY")
        .workplane(offset=PLATE_H)
        .circle(WASHER_D / 2)
        .extrude(WASHER_H)
    )

    # 上ワッシャー（ターンテーブル上面）
    tt_z = PLATE_H + WASHER_H + SPACER_H
    washer_top = (
        cq.Workplane("XY")
        .workplane(offset=tt_z + PLATE_H)
        .circle(WASHER_D / 2)
        .extrude(WASHER_H)
    )

    result = bolt.union(spacer).union(washer_bottom).union(washer_top)
    return result


def make_link_arm():
    """
    リンクアーム
    - サーボホーンの穴 → ターンテーブル端の穴を結ぶプッシュロッド
    - M3ボルト + スペーサーで構成
    - 両端にピボット（回転自由）
    """
    # プッシュロッド本体（単純な棒で表現）
    rod = (
        cq.Workplane("XY")
        .circle(LINK_ROD_D / 2)
        .extrude(LINK_ARM_LEN)
    )

    # 両端のピボットジョイント（スペーサー表現）
    for z in [0, LINK_ARM_LEN]:
        joint = (
            cq.Workplane("XY")
            .workplane(offset=z - 1.5)
            .circle(3.0)
            .extrude(3.0)
        )
        rod = rod.union(joint)

    return rod


def make_servo_horn():
    """サーボホーン（シングルアーム、簡易モデル）"""
    horn = (
        cq.Workplane("XY")
        .rect(5, 20)
        .extrude(2)
    )
    # 軸穴
    horn = horn.cut(
        cq.Workplane("XY")
        .circle(2.4)
        .extrude(2)
    )
    # 先端穴（リンク接続）
    horn = horn.cut(
        cq.Workplane("XY")
        .transformed(offset=(0, 8, 0))
        .circle(1.5)
        .extrude(2)
    )
    return horn


def make_assembly():
    """
    全体アセンブリ
    """
    assy = cq.Assembly()

    # --- 1. ベースプレート ---
    base = make_base_plate()
    assy.add(base, name="base_plate", color=cq.Color(0.85, 0.82, 0.75, 1.0))  # タミヤプレート色

    # --- 2. 中心回転軸 ---
    shaft = make_center_shaft()
    assy.add(shaft, name="center_shaft",
             loc=cq.Location((0, 0, 0)),
             color=cq.Color(0.7, 0.7, 0.7, 1.0))  # シルバー

    # --- 3. ターンテーブル ---
    tt_z = PLATE_H + WASHER_H + SPACER_H  # ベース上面 + ワッシャー + スペーサー
    turntable = make_turntable()
    assy.add(turntable, name="turntable",
             loc=cq.Location((0, 0, tt_z)),
             color=cq.Color(0.85, 0.82, 0.75, 0.8))  # 半透明プレート色

    # --- 4. Yawサーボ（ベースに横付け） ---
    # サーボは横倒し（Z軸回りに配置）、軸がZ+を向く
    # ベースプレート上面にフランジで固定
    servo = make_mg90s()
    # サーボを配置: 軸がZ+を向いたまま、ベース上に横付け
    # サーボのシャフトがZ+方向、ベースプレート上に設置
    servo_x = SERVO_OFFSET_X
    servo_y = 0
    servo_z = PLATE_H  # ベース上面
    assy.add(servo, name="yaw_servo",
             loc=cq.Location((servo_x, servo_y, servo_z)),
             color=cq.Color(0.2, 0.3, 0.8, 1.0))  # 青

    # --- 5. リンクアーム ---
    # サーボホーン先端(servo_x + horn_reach, 0) → ターンテーブル端(link_attach_x, 0)
    horn_reach = 8.0  # サーボホーン先端までの距離
    servo_shaft_x = servo_x + SERVO_SHAFT_OFFSET_X
    link_start_x = servo_shaft_x + horn_reach
    link_start_z = servo_z + SERVO_BODY_H + SERVO_SHAFT_H + 2  # シャフト上

    link_end_x = LINK_ATTACH_OFFSET  # ターンテーブル端寄りの穴
    link_end_z = tt_z + PLATE_H / 2

    # リンクの角度と長さを計算
    dx = link_end_x - link_start_x
    dz = link_end_z - link_start_z
    link_len = math.sqrt(dx * dx + dz * dz)
    link_angle = math.degrees(math.atan2(dz, dx))

    link = make_link_arm()
    assy.add(link, name="link_arm",
             loc=cq.Location(
                 (link_start_x, 0, link_start_z),
                 (0, -link_angle, 0)
             ),
             color=cq.Color(0.9, 0.4, 0.1, 1.0))  # オレンジ

    # --- 6. サーボホーン ---
    horn = make_servo_horn()
    horn_z = servo_z + SERVO_BODY_H + SERVO_SHAFT_H
    assy.add(horn, name="servo_horn",
             loc=cq.Location((servo_shaft_x, 0, horn_z)),
             color=cq.Color(1, 1, 1, 1.0))  # 白

    # --- 7. パンチルトブラケット位置の参考マーカー ---
    # ターンテーブル上にパンチルトが載る位置を示す
    pt_marker = (
        cq.Workplane("XY")
        .box(38.9, 18.8, 2, centered=(True, True, False))
    )
    pt_z = tt_z + PLATE_H
    assy.add(pt_marker, name="pantilt_footprint",
             loc=cq.Location((0, 0, pt_z)),
             color=cq.Color(0.3, 0.8, 0.3, 0.4))  # 半透明グリーン

    # --- 8. CoreS3 位置の参考マーカー ---
    cores3_marker = (
        cq.Workplane("XY")
        .box(54, 54, 3, centered=(True, True, False))
    )
    cores3_z = pt_z + 30  # パンチルト高さ概算
    assy.add(cores3_marker, name="cores3_footprint",
             loc=cq.Location((0, 0, cores3_z)),
             color=cq.Color(0.2, 0.2, 0.2, 0.3))  # 半透明ダーク

    return assy


def export_individual_parts():
    """個別パーツをSTEP/STLエクスポート"""
    out_dir = os.path.join(os.path.dirname(__file__), "yaw_link_parts")
    os.makedirs(out_dir, exist_ok=True)

    print("=== ヨー軸リンク機構 パーツエクスポート ===\n")

    # ベースプレート
    base = make_base_plate()
    cq.exporters.export(base, os.path.join(out_dir, "base_plate.step"))
    print(f"  base_plate.step  ({BASE_W:.1f} × {BASE_D:.1f} × {PLATE_H:.1f} mm)")
    print(f"    穴: {BASE_HOLES_X} × {BASE_HOLES_Y} = {BASE_HOLES_X * BASE_HOLES_Y} 穴")

    # ターンテーブル
    tt = make_turntable()
    cq.exporters.export(tt, os.path.join(out_dir, "turntable.step"))
    print(f"  turntable.step   ({TT_W:.1f} × {TT_D:.1f} × {PLATE_H:.1f} mm)")
    print(f"    穴: {TT_HOLES_X} × {TT_HOLES_Y} = {TT_HOLES_X * TT_HOLES_Y} 穴")

    print(f"\n  中心軸: M3ボルト + Φ{SPACER_OD}スペーサー (h={SPACER_H}mm)")
    print(f"  ベース〜ターンテーブル間隔: {WASHER_H + SPACER_H + WASHER_H:.1f}mm")
    print(f"  サーボ位置: ベース中心から X={SERVO_OFFSET_X}mm")
    print(f"  リンク接続: ターンテーブル中心から {LINK_ATTACH_OFFSET}mm")

    return out_dir


# ============================================
#  メイン
# ============================================
if __name__ == "__main__":
    # 個別パーツ
    out_dir = export_individual_parts()

    # アセンブリ
    print("\nAssembling...")
    assy = make_assembly()

    assy_path = os.path.join(os.path.dirname(__file__), "yaw_link_assembly.step")
    assy.save(assy_path)
    print(f"\n  Assembly: yaw_link_assembly.step")

    print("\n=== 完了 ===")
    print(f"""
重量の流れ:
  CoreS3 (~120g) → パンチルトブラケット → ターンテーブル
    → 中心軸 (M3ボルト+スペーサー) → ベースプレート
  サーボ軸には回転トルクのみ！

組み立て手順:
  1. ベースプレートを切り出す ({BASE_HOLES_X}×{BASE_HOLES_Y}穴 = {BASE_W:.1f}×{BASE_D:.1f}mm)
  2. ターンテーブルを切り出す ({TT_HOLES_X}×{TT_HOLES_Y}穴 = {TT_W:.1f}×{TT_D:.1f}mm)
  3. ベース中央穴にM3ボルト+スペーサーを立てる
  4. ターンテーブルをスペーサー上に載せ、ワッシャー+ナットで軽く締める
  5. MG90Sをベースに横付け固定（フランジ穴→プレート穴にM2ネジ）
  6. サーボホーン先端 → ターンテーブル端の穴にM3プッシュロッドを接続
  7. パンチルトブラケットをターンテーブル上にネジ止め
""")

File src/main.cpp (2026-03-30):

#include <M5CoreS3.h>
#include <Wire.h>
#include <WiFi.h>
#include <ArduinoOTA.h>
#include <ESPmDNS.h>
#include <AsyncTCP.h>
#include <ESPAsyncWebServer.h>

AsyncWebServer webServer(80);
AsyncWebSocket wsLog("/log");

// Log to both Serial and WebSocket clients
template<typename... Args>
void LOG(const char* fmt, Args... args) {
    Serial.printf(fmt, args...);
    char buf[256];
    snprintf(buf, sizeof(buf), fmt, args...);
    wsLog.textAll(buf);
}

static const char LOG_PAGE[] PROGMEM = R"rawlit(<!DOCTYPE html><html><head>
<meta charset="utf-8"><title>CoreS3 Log</title>
<style>body{background:#111;color:#0f0;font-family:monospace;font-size:13px;margin:0;padding:8px}
#log{white-space:pre-wrap;word-break:break-all}</style></head><body>
<div id="log"></div><script>
var ws=new WebSocket('ws://'+location.host+'/log');
var el=document.getElementById('log');
ws.onmessage=function(e){el.textContent+=e.data;window.scrollTo(0,document.body.scrollHeight);};
</script></body></html>)rawlit";
#include "face.h"
#include "camera_detect.h"
#include "wifi_config.h"

#ifdef ENABLE_VOICE_CHAT
#include "voice_chat.h"
VoiceChat voiceChat;
#endif

Face face;
CameraDetect camDetect;

// --- IMU (tilt detection) ---
float imuTilt = 0;        // 0=horizontal, 90=vertical, 180=upside down
float imuSmoothed = 0;
static const float IMU_ALPHA = 0.15f;  // smoothing

// --- Sound effects (simple single tone) ---
unsigned long micMuteUntil = 0;
unsigned long soundCooldown = 0;
static const unsigned long SOUND_COOLDOWN_MS = 2000;  // min 2s between sounds

// Pre-computed short beep buffers (avoids blocking tone generation)
static const int BEEP_SAMPLES = 800;  // 50ms at 16kHz
int16_t beepBuf[BEEP_SAMPLES];

void generateBeep(float freq, int samples, int16_t* buf) {
    for (int i = 0; i < samples; i++) {
        float t = (float)i / 16000.0f;
        float env = 1.0f - (float)i / samples;  // fade out
        buf[i] = (int16_t)(sinf(2.0f * M_PI * freq * t) * 8000 * env);
    }
}

void playSoundForExpression(Expression expr) {
    unsigned long now = millis();
    if (!CoreS3.Speaker.isEnabled()) return;
    if (now < soundCooldown) return;

    float freq;
    int samples;
    switch (expr) {
        case Expression::HAPPY:    freq = 1500; samples = 640;  break;  // 40ms
        case Expression::SAD:      freq = 500;  samples = 800;  break;  // 50ms
        case Expression::SURPRISED:freq = 2200; samples = 480;  break;  // 30ms
        case Expression::LOVE:     freq = 1200; samples = 640;  break;  // 40ms
        default: return;
    }

    generateBeep(freq, samples, beepBuf);
    CoreS3.Speaker.setVolume(50);
    CoreS3.Speaker.playRaw(beepBuf, samples, 16000, false, 1, 0);

    soundCooldown = now + SOUND_COOLDOWN_MS;
    micMuteUntil = now + 500;
}

// --- Microphone ---
static const int MIC_SAMPLES = 160;
int16_t micBuf[MIC_SAMPLES];
float micAvgLevel = 500;
bool micReady = false;
static const float MIC_SPIKE_RATIO = 3.0f;
static const float MIC_MIN_PEAK = 3000.0f;

// Touch
unsigned long lastTouchTime = 0;
bool touchHeld = false;
static const unsigned long LONG_PRESS_MS = 600;

// Detection timing
unsigned long lastDetectTime = 0;
static const unsigned long DETECT_INTERVAL_MS = 200;

// --- Smoothing: moving average over N frames ---
static const int AVG_FRAMES = 5;
float areaHistory[AVG_FRAMES] = {};
float motionHistory[AVG_FRAMES] = {};
float skinHistory[AVG_FRAMES] = {};
bool faceHistory[AVG_FRAMES] = {};
int historyIdx = 0;
int historyCount = 0;

struct SmoothedResult {
    float area;
    float motion;
    float skin;
    float faceRate;  // fraction of recent frames with face detected
};

SmoothedResult getSmoothed() {
    SmoothedResult s = {};
    int n = min(historyCount, AVG_FRAMES);
    if (n == 0) return s;
    for (int i = 0; i < n; i++) {
        s.area += areaHistory[i];
        s.motion += motionHistory[i];
        s.skin += skinHistory[i];
        s.faceRate += faceHistory[i] ? 1.0f : 0.0f;
    }
    s.area /= n;
    s.motion /= n;
    s.skin /= n;
    s.faceRate /= n;
    return s;
}

void pushHistory(const DetectResult &r) {
    areaHistory[historyIdx] = r.areaRatio;
    motionHistory[historyIdx] = r.motionLevel;
    skinHistory[historyIdx] = r.skinRatio;
    faceHistory[historyIdx] = r.faceDetected;
    historyIdx = (historyIdx + 1) % AVG_FRAMES;
    if (historyCount < AVG_FRAMES) historyCount++;
}

// Presence levels
enum class Presence : uint8_t {
    NONE = 0,
    MOTION_ONLY = 1,
    FACE_FAR = 2,
    FACE_MID = 3,
    CLOSE = 4,
};

Presence currentPresence = Presence::NONE;

#include "servo_ctrl.h"
ServoCtrl servoCtrl;
unsigned long lastPresenceTime = 0;

// Expression transition: require stable state for N ms before switching
static const unsigned long EXPR_SETTLE_MS = 600;  // hold new state 0.6s before switching
Expression targetExpression = Expression::NORMAL;
Expression currentExpression = Expression::NORMAL;
unsigned long targetSince = 0;

static const unsigned long SURPRISED_DURATION_MS = 800;
static const unsigned long SAD_DURATION_MS = 3000;
static const unsigned long SLEEPY_DELAY_MS = 5000;
unsigned long surprisedUntil = 0;
bool wasPresent = false;
bool cameraActive = false;

int8_t faceXToGaze(int faceX) {
    // Wider range for more visible eye movement
    return (int8_t)constrain(-(faceX - 160) / 8, -12, 12);
}
int8_t faceYToGaze(int faceY) {
    return (int8_t)constrain((faceY - 120) / 12, -6, 6);
}

Presence evaluatePresence(const SmoothedResult &s) {
    // Face visible in most recent frames
    bool faceVisible = s.faceRate >= 0.4f;

    if (faceVisible) {
        if (s.area > 0.30f) return Presence::CLOSE;
        if (s.area > 0.20f) return Presence::FACE_MID;
        return Presence::FACE_FAR;
    }

    // No face — use motion
    if (s.motion >= 0.45f) return Presence::CLOSE;
    if (s.motion >= 0.30f) return Presence::MOTION_ONLY;

    return Presence::NONE;
}

Expression presenceToExpression(Presence p, unsigned long now) {
    switch (p) {
        case Presence::CLOSE:
            return Expression::LOVE;
        case Presence::FACE_MID:
        case Presence::MOTION_ONLY:
            return Expression::HAPPY;
        case Presence::FACE_FAR:
            return Expression::NORMAL;
        case Presence::NONE: {
            if (lastPresenceTime == 0) return Expression::NORMAL;
            unsigned long elapsed = now - lastPresenceTime;
            if (elapsed < SAD_DURATION_MS) return Expression::SAD;
            if (elapsed < SLEEPY_DELAY_MS) return Expression::SAD;
            return Expression::SLEEPY;
        }
    }
    return Expression::NORMAL;
}
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

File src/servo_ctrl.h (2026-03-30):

#pragma once
#include <Wire.h>
#include <Adafruit_PWMServoDriver.h>
#include "expressions.h"

// Forward declaration — Presence is defined in main.cpp
enum class Presence : uint8_t;

class ServoCtrl {
public:
    // Channel assignment
    static constexpr int CH_YAW   = 0;
    static constexpr int CH_TILT  = 1;
    static constexpr int CH_ARM_L = 2;
    static constexpr int CH_ARM_R = 3;

    // Servo limits (degrees)
    static constexpr float YAW_MIN  = 45.0f;
    static constexpr float YAW_MAX  = 135.0f;
    static constexpr float YAW_CENTER = 90.0f;
    static constexpr float TILT_MIN = 60.0f;
    static constexpr float TILT_MAX = 120.0f;
    static constexpr float TILT_CENTER = 90.0f;
    static constexpr float ARM_MIN  = 40.0f;
    static constexpr float ARM_MAX  = 140.0f;
    static constexpr float ARM_CENTER = 90.0f;

    // Pulse range (MG90S)
    static constexpr int SERVO_MIN_US = 500;
    static constexpr int SERVO_MAX_US = 2400;
    static constexpr int SERVO_FREQ   = 50;

    // Movement speeds (degrees per update call)
    static constexpr float NORMAL_SPEED = 2.0f;
    static constexpr float FAST_SPEED   = 10.0f;

    // Idle motion
    static constexpr unsigned long IDLE_INTERVAL_MS = 3000;

    bool begin() {
        Wire.beginTransmission(0x40);
        _connected = (Wire.endTransmission() == 0);
        if (!_connected) return false;

        _pwm.begin();
        _pwm.setOscillatorFrequency(25000000);
        _pwm.setPWMFreq(SERVO_FREQ);
        delay(100);

        // All servos to center
        for (int i = 0; i < 4; i++) {
            _current[i] = 90.0f;
            _target[i] = 90.0f;
            writeAngle(i, 90.0f);
        }
        return true;
    }

    bool isConnected() const { return _connected; }

    void update(Expression expr, Presence presence, bool faceDetected,
                int faceCenterX, int faceCenterY) {
        if (!_connected) return;

        unsigned long now = millis();
        _expr = expr;
        _presence = presence;

        // --- Neck: head tracking or idle ---
        updateNeck(faceDetected, faceCenterX, faceCenterY, now);

        // --- Arms: expression-driven animation ---
        updateArms(now);

        // --- Move servos toward targets ---
        for (int i = 0; i < 4; i++) {
            float speed = _speed[i];
            if (_current[i] != _target[i]) {
                float diff = _target[i] - _current[i];
                if (fabsf(diff) <= speed) {
                    _current[i] = _target[i];
                } else {
                    _current[i] += (diff > 0) ? speed : -speed;
                }
                writeAngle(i, _current[i]);
            }
        }
    }

private:
    Adafruit_PWMServoDriver _pwm = Adafruit_PWMServoDriver(0x40, Wire);
    bool _connected = false;
    Expression _expr = Expression::NORMAL;
    Presence _presence = (Presence)0;

    float _current[4] = {90, 90, 90, 90};
    float _target[4]  = {90, 90, 90, 90};
    float _speed[4]   = {NORMAL_SPEED, NORMAL_SPEED, NORMAL_SPEED, NORMAL_SPEED};

    // Idle state
    unsigned long _lastIdleChange = 0;
    float _idleYawTarget = 90.0f;
    float _idleTiltTarget = 90.0f;

    // Arm animation state
    unsigned long _armAnimStart = 0;
    Expression _prevArmExpr = Expression::NORMAL;

    void writeAngle(int channel, float angle) {
        int a = constrain((int)angle, 0, 180);
        _pwm.writeMicroseconds(channel, map(a, 0, 180, SERVO_MIN_US, SERVO_MAX_US));
    }

    // --- Neck logic ---
    void updateNeck(bool faceDetected, int fx, int fy, unsigned long now) {
        _speed[CH_YAW] = NORMAL_SPEED;
        _speed[CH_TILT] = NORMAL_SPEED;

        if (_expr == Expression::SLEEPY) {
            // Droopy: tilt head down, yaw center
            _target[CH_YAW] = YAW_CENTER;
            _target[CH_TILT] = 75.0f;
            return;
        }

        if (faceDetected) {
            // Track face
            // Camera image is mirrored, so invert X
            // X: 0(left edge)→135°, 160(center)→90°, 320(right edge)→45°
            float yaw = mapFloat((float)fx, 0.0f, 320.0f, YAW_MAX, YAW_MIN);
            // Y: 0(top)→110°, 120(center)→90°, 240(bottom)→70°
            float tilt = mapFloat((float)fy, 0.0f, 240.0f, 110.0f, 70.0f);

            _target[CH_YAW]  = constrain(yaw, YAW_MIN, YAW_MAX);
            _target[CH_TILT] = constrain(tilt, TILT_MIN, TILT_MAX);
            _lastIdleChange = now;  // reset idle timer
            return;
        }

        // No face, no presence → idle look-around
        if ((uint8_t)_presence == 0) {  // Presence::NONE
            if (now - _lastIdleChange >= IDLE_INTERVAL_MS) {
                _lastIdleChange = now;
                // Random target within a gentle range
                _idleYawTarget = YAW_CENTER + (float)(random(-30, 31));
                _idleTiltTarget = TILT_CENTER + (float)(random(-10, 11));
                _idleYawTarget = constrain(_idleYawTarget, YAW_MIN, YAW_MAX);
                _idleTiltTarget = constrain(_idleTiltTarget, TILT_MIN, TILT_MAX);
            }
            _target[CH_YAW] = _idleYawTarget;
            _target[CH_TILT] = _idleTiltTarget;
            _speed[CH_YAW] = 1.0f;   // slow idle motion
            _speed[CH_TILT] = 1.0f;
        } else {
            // Someone nearby but no face detected — hold last position
        }
    }

    // --- Arm logic ---
    void updateArms(unsigned long now) {
        // Reset animation timer on expression change
        if (_expr != _prevArmExpr) {
            _armAnimStart = now;
            _prevArmExpr = _expr;
        }

        float elapsed = (float)(now - _armAnimStart);
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

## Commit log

2026-03-30 Initial commit: CoreS3 companion robot with voice chat
    Full companion robot firmware including face display, camera detection,
    servo control, IMU tilt sensing, and Gemini API voice chat module.
    Voice chat (ENABLE_VOICE_CHAT): touch to record -> Gemini API -> speaker playback.
    Can be omitted by removing -DENABLE_VOICE_CHAT from build_flags.
    [base.step, base.stl, body.step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]
2026-04-06 Add yaw link mechanism design and robot skill
    - CadQuery model for yaw axis link mechanism using Tamiya universal plate
    - STEP exports for base plate, turntable, and full assembly
    - Claude Code robot skill for ongoing development
    - Project README
    [base_plate.step, turntable.step, yaw_link_assembly.step]
2026-04-24 Add SKILL.md for Claude.ai skill trigger
    Document the project so Claude.ai can auto-engage when the user
    discusses this robot prototype: goals, current phase, stack,
    repo layout, Claude's expected role, and known gotchas.
